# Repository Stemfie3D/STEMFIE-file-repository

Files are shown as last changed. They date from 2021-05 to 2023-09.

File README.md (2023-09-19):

# STEMFIE-file-repository
### The official file repository of the STEMFIE construction-set toy



**STEMFIE** is an open-sourced educational construction-set toy you can download and make using an affordable off-the-shelf 3D printer. 

Inspired by the vintage toy [Meccano](https://en.wikipedia.org/wiki/Meccano), I designed each component as a part of a mechanical ecosystem of compatible shapes defined to interlock through various connections and fasteners.

This file repository contains mainly the three following file types.

* **.STL** - Commonly used for single parts, you can import them into your 3D printer's slicing software or your 3D modeling/CAD software.
* **.3mf** - Commonly used for single parts and ready-to-print nested build plates.
* **.stpZ** - Used for single parts describing the non-destructive shape and form of the part's design. Use this file to import it into your CAD software. If it can't open .stpZ, please download [FreeCAD](https://freecad.org) to open the files.
* **.FCStd** - The original project file of parts and assemblies containing the parametric data for generating the part's shape. FCStd is FreeCAD's native file format.
* **.SVG** - Files describing two-dimensional contours and shapes as vector-based data. Most SVG files in this repository represent 1/4th BlockUnit parts (such as braces) that can be made using a laser cutter.  

The shape and orientation of every STEMFIE file are optimized for 3D printing without the need for support structures on a filament-based 3D printer.

All 3D files and graphics are made in [FreeCAD](https://github.com/FreeCAD/FreeCAD), [Blender](https://github.com/blender/blender), [Inkscape](https://inkscape.org), and [Krita](https://krita.org).

### The STEMFIE Project's Online Places

* [ Official Website](https://stemfie.org)
* [Telegram](http://t.me/stemfie3d)
* [Twitter](https://twitter.com/Stemfie3D)
* [Instagram](https://instagram.com/Stemfie3D)
* [Facebook](https://facebook.com/Stemfie3D)

### Contact Informaiton
* **Paulo Kiefe** (paulo@stemfie.org)

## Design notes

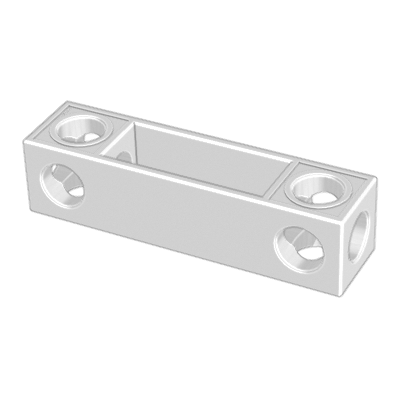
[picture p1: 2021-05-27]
Beams/Straight/Box-section/Beam STR BXS ESS (thumbnail).png

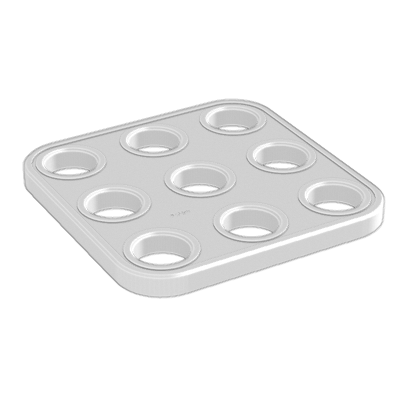
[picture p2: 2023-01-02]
Plates/4 - Square/Plate SQR (thumbnail).png

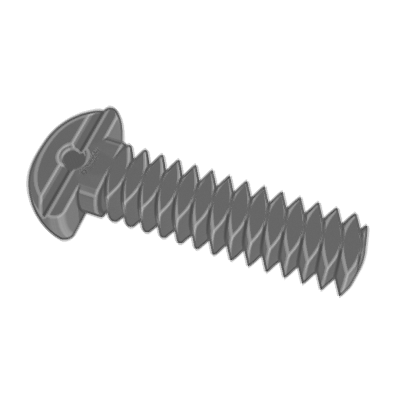
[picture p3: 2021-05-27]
Fasteners/Screws/Fully Threaded Rounded Head/Screw FL-RH RHD (thumbnail).png

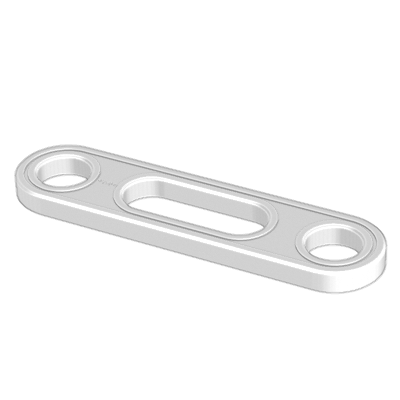
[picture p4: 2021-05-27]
Braces/Straight/Slotted Centered/Brace STR SLT CNT ERR (thumbnail).png

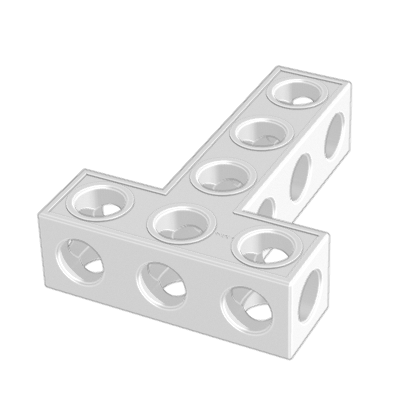
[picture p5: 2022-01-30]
Beams/Angled/T-shaped Symmetric/Beam AGD TSH SYM ESS (thumbnail).png

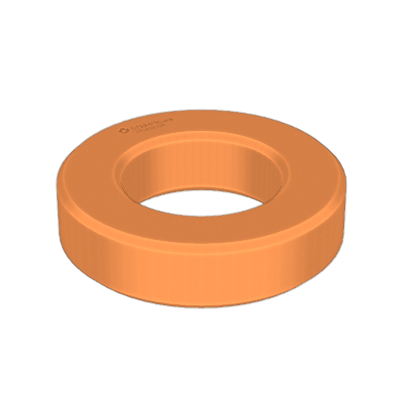
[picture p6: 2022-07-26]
Fasteners/Washers/Free/Washer FRE (thumbnail).png

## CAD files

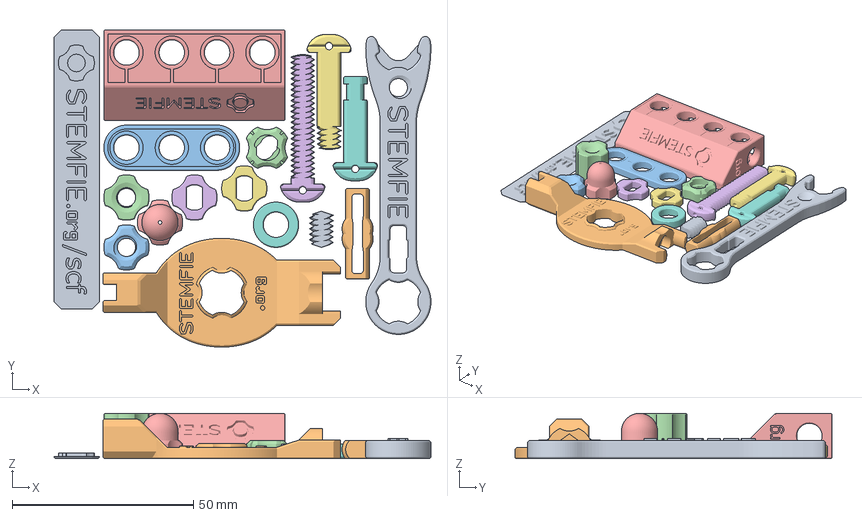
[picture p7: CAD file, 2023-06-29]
3D-printing/Calibration/STEMFIE Calibration File/STEMFIE Calibration File (stemfie.org).3mf
104.0 x 87.5 x 12.5 mm
STEMFIE Calibration File (stemfie.org).stl_1
STEMFIE Calibration File (stemfie.org).stl_2
STEMFIE Calibration File (stemfie.org).stl_3
STEMFIE Calibration File (stemfie.org).stl_4
STEMFIE Calibration File (stemfie.org).stl_5
STEMFIE Calibration File (stemfie.org).stl_6
STEMFIE Calibration File (stemfie.org).stl_7
STEMFIE Calibration File (stemfie.org).stl_8
STEMFIE Calibration File (stemfie.org).stl_9
STEMFIE Calibration File (stemfie.org).stl_10
STEMFIE Calibration File (stemfie.org).stl_11
STEMFIE Calibration File (stemfie.org).stl_12
STEMFIE Calibration File (stemfie.org).stl_13
STEMFIE Calibration File (stemfie.org).stl_14
STEMFIE Calibration File (stemfie.org).stl_15
STEMFIE Calibration File (stemfie.org).stl_16
STEMFIE Calibration File (stemfie.org).stl_17

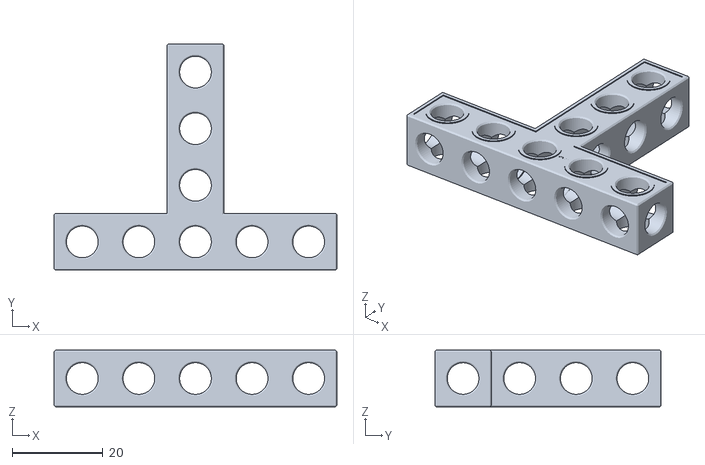
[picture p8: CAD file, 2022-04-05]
Beams/Angled/T-shaped Symmetric/Beam AGD TSH SYM ESS BU05x04x01 - SPN-BEM-1021 (stemfie.org).stl
62.5 x 50.0 x 12.5

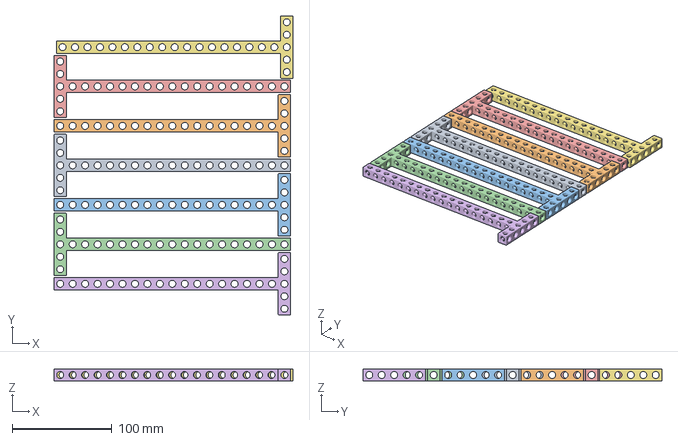
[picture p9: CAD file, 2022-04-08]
Beams/Angled/T-shaped Symmetric/Build Plates/Beam AGD TSH SYM ESS BU05x19x01 - SPN-BEM-1036 (stemfie.org) 7x 3D-printing build plate.3mf
239.9 x 300.0 x 12.5 mm

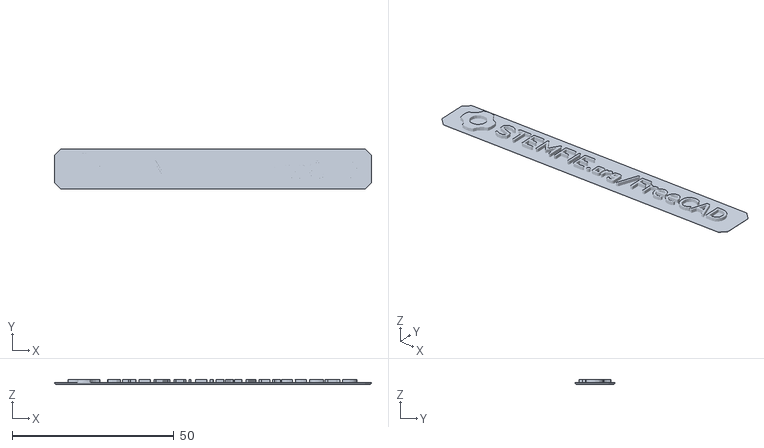
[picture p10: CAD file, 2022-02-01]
Beams/Angled/T-shaped Symmetric/CAD/- You can use the open-source FreeCAD.org software to import and edit .stpZ files.stl
98.0 x 12.5 x 1.56

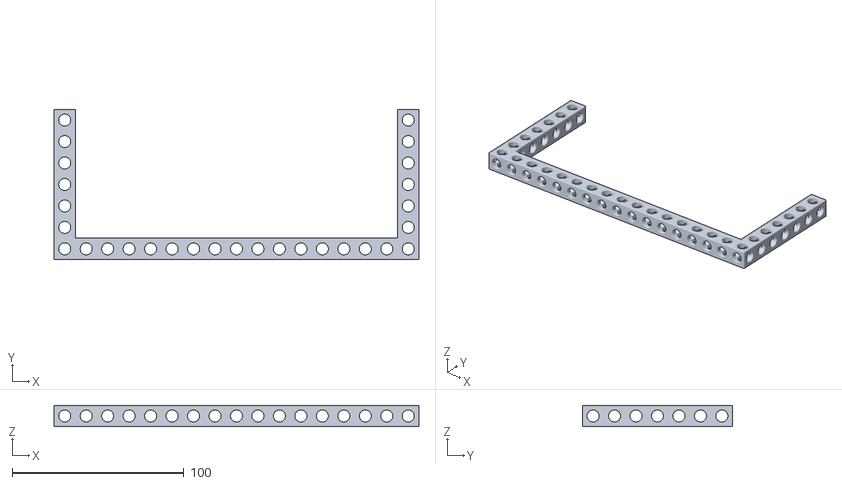
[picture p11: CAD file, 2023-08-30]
Beams/Angled/U-shaped Symmetric/Beam AGD USH SYM ESS BU17x07x01 - SPN-BEM-0580 (stemfie.org).stl
212.5 x 87.5 x 12.5

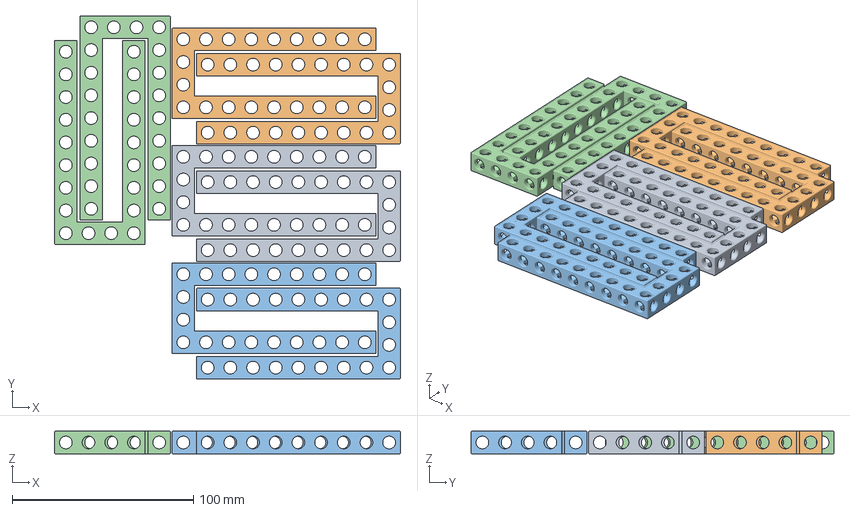
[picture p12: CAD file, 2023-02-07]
Beams/Angled/U-shaped Symmetric/Build Plates/Beam AGD USH SYM ESS BU04x09x01 - SPN-BEM-0327 (stemfie.org) 8x 3D Printing Build Plate.3mf
190.7 x 200.0 x 12.5 mm

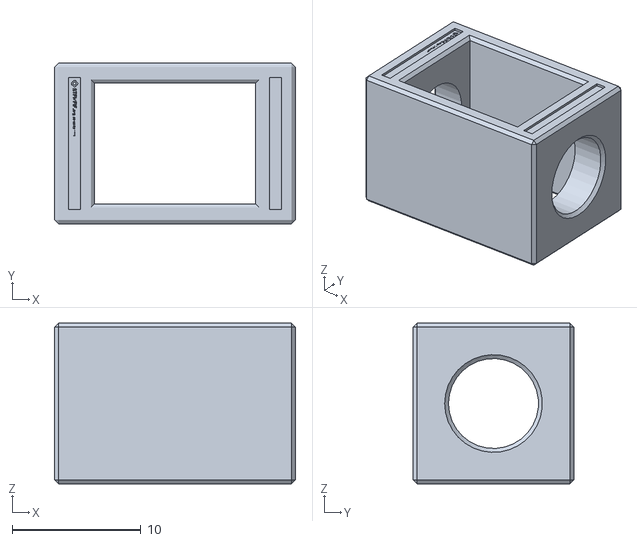
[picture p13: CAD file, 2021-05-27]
Beams/Straight/Box-section/Beam STR BXS ESS BU01.50x01.00x01.00x00.25x00.125 - SPN-BEM-0003 (stemfie.org).stl
18.8 x 12.5 x 12.5

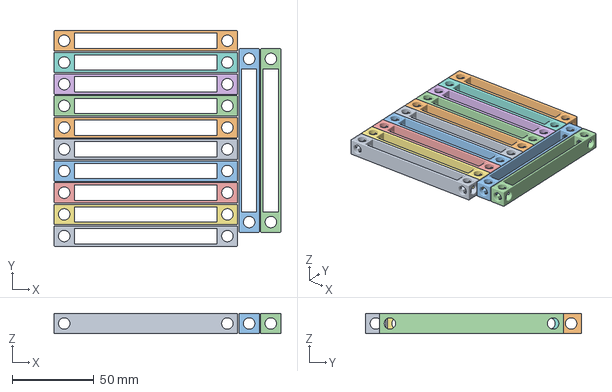
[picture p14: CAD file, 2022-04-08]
Beams/Straight/Box-section/Build Plates/Beam STR BXS ESS BU09.00x01.00x01.00x01.00x00.125 - SPN-BEM-0406 (stemfie.org) 12x 3D-printing build plate.3mf
139.1 x 132.2 x 12.5 mm

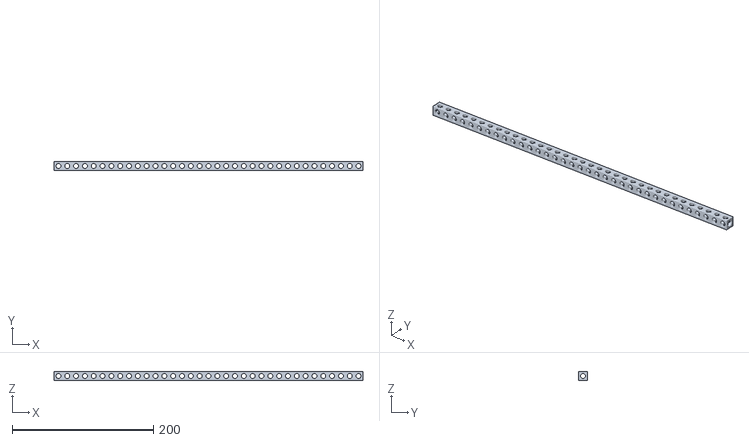
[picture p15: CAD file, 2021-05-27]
Beams/Straight/Square Endings/Beam STR ESS BU35x01x01 - SPN-BEM-0072 (stemfie.org).stl
437.5 x 12.5 x 12.5

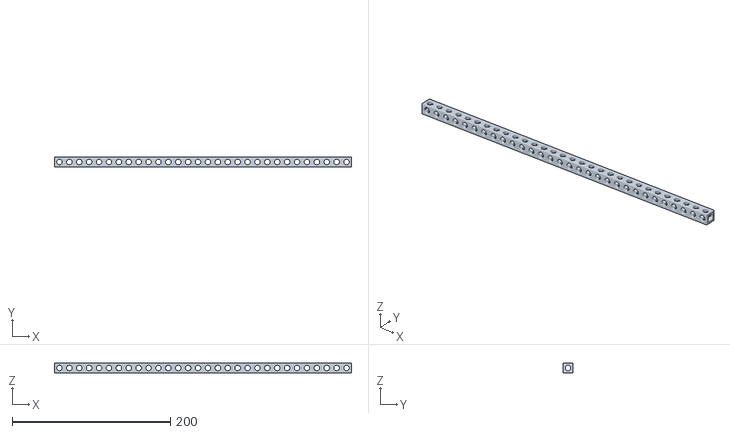
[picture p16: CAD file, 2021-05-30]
Beams/Straight/Square Ends/Beam STR ESS BU30x01x01 - SPN-BEM-0067 (stemfie.org).stl
375.0 x 12.5 x 12.5

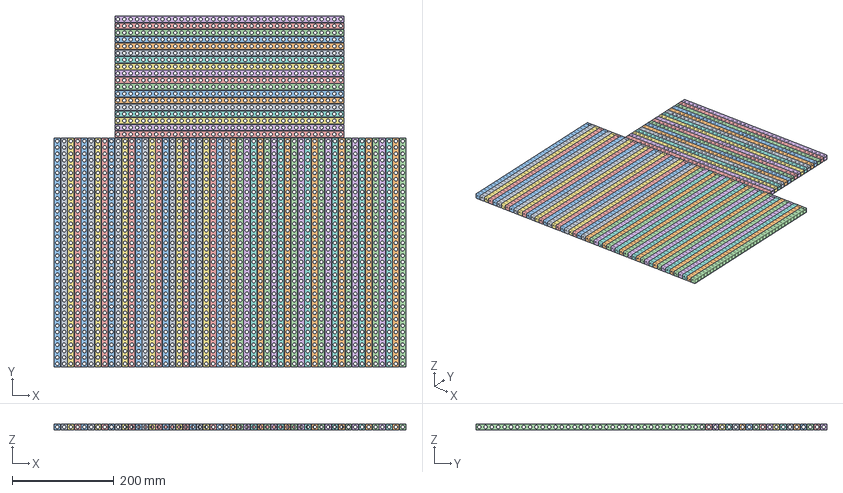
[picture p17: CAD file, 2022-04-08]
Beams/Straight/Square Ends/Build Plates/Beam STR ESS BU36x01x01 - SPN-BEM-0073 (stemfie.org) 70x 3D-printing build plate.3mf
690.8 x 689.4 x 12.5 mm

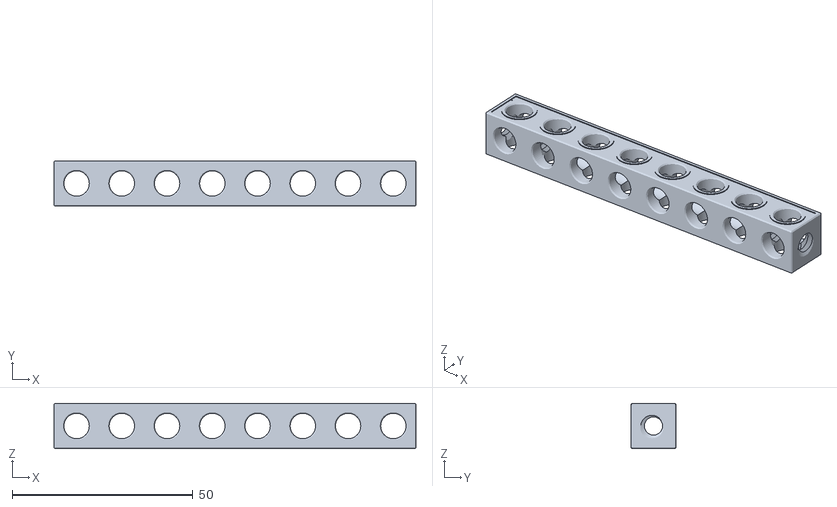
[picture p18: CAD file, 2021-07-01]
Beams/Straight/Threaded Ends/Beam STR ERHRH DE ESS BU08x01x01 - SPN-BEM-0807 (stemfie.org).stl
100.0 x 12.5 x 12.5

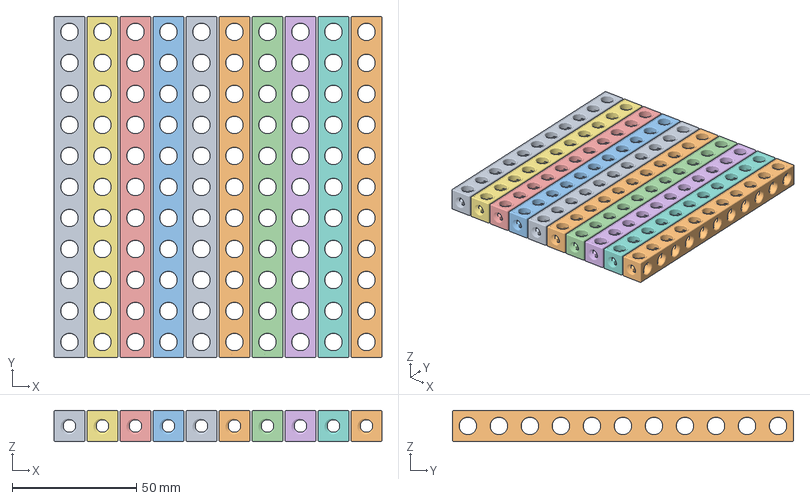
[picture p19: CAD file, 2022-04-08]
Beams/Straight/Threaded Ends/Build Plates/Beam STR ERHRH DE ESS BU11x01x01 - SPN-BEM-0810 (stemfie.org) 10x 3D-printing build plate.3mf
132.2 x 137.5 x 12.5 mm

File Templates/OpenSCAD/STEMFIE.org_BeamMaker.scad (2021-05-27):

//OpenSCAD script for creating Stemife.org construction beams
//Feel free to adapt and improve and share your OpenSCAD script (please send contact me)
//Contact: paulo.kiefe@stemfie.org (https://stemfie.org)


//Number of BlockUnits in the X direction
    BSX=5;
//Number of BlockUnits in the Y direction
    BSY=1; 
//Number of BlockUnits in the Z direction 
    BSZ=1; 
    
//Universal values
    BU=12.5; //Universal voxel block unit (mm) in Stemfie (BlockUnit)
    Hole=3.5; //Universal radius (mm) of the connection hole
    SurfTess=32; //Universal tesselation value of curved surfaces
    ChamferHole=2.45; //Chamfer size adjustment value for connection holes
    ChamferEdge=BU*1.25; //Chamfer size adjustment value for outer edges

difference(){
    cube([BU*BSX, BU*BSY, BU*BSZ]);   
        for(i = [0:BSX-1]){
            translate([i*BU,0,0]) XHoles();
        }
        for(i = [0:BSY-1]){
            translate([0,i*BU,0]) YHoles();
        }
        ZArray();
}



//MODULES
module XHoles(){
    union(){
        translate([BU/2,-ChamferHole,BU/2]) rotate([270,0,0]) cylinder(h=BU/2, r1=BU/2, r2=0, $fn=SurfTess);
        translate([BU/2,ChamferHole+BSY*BU,BU/2]) rotate([90,0,0]) cylinder(h=BU/2, r1=BU/2, r2=0, $fn=SurfTess);
        translate([BU/2,0,BU/2]) rotate([270,0,0]) cylinder(r=Hole, h=BSY*BU, $fn=SurfTess);
    }
}

module YHoles(){
    union(){
        translate([0,BU/2,BU/2]) rotate([0,90,0]) cylinder(r=Hole, h=BSX*BU, $fn=SurfTess);
        translate([-ChamferHole,BU/2,BU/2]) rotate([0,90,0]) cylinder(h=BU/2, r1=BU/2, r2=0, $fn=SurfTess);
        translate([ChamferHole+BSX*BU,BU/2,BU/2]) rotate([0,270,0]) cylinder(h=BU/2, r1=BU/2, r2=0, $fn=SurfTess);
    }
}
module ZHoles(){
    union(){
        translate([BU/2,BU/2,-ChamferHole]) rotate([0,0,0]) cylinder(h=BU/2, r1=BU/2, r2=0, $fn=SurfTess);
        translate([BU/2,BU/2,ChamferHole+BU]) rotate([180,0,0]) cylinder(h=BU/2, r1=BU/2, r2=0, $fn=SurfTess);
        translate([BU/2,BU/2,0]) rotate([0,0,0]) cylinder(r=Hole, h=BU, $fn=SurfTess);
    }
}

module ZArray(){
    for(a = [0:BSX-1]){
        translate([a*BU,0,0]){
            for(i = [0:BSY-1]){
            translate([0,i*BU,0]) ZHoles();
            }
        }
    }
}

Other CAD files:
3D-printing/Samples/STEMFIE.org Quick-print sample/STEMFIE.org Quick-print sample [shoulder-screw, pin, nut, washers, brace].3mf
3D-printing/Samples/STEMFIE.org Quick-print sample/STEMFIE.org Quick-print sample [shoulder-screw, pin, nut, washers, brace].stl
Beams/Angled/T-shaped Symmetric/Beam AGD TSH SYM ESS BU03x02x01 - SPN-BEM-1000 (stemfie.org).stl
Beams/Angled/T-shaped Symmetric/Beam AGD TSH SYM ESS BU03x03x01 - SPN-BEM-1001 (stemfie.org).stl
Beams/Angled/T-shaped Symmetric/Beam AGD TSH SYM ESS BU03x04x01 - SPN-BEM-1002 (stemfie.org).stl
Beams/Angled/T-shaped Symmetric/Beam AGD TSH SYM ESS BU03x05x01 - SPN-BEM-1003 (stemfie.org).stl
Beams/Angled/T-shaped Symmetric/Beam AGD TSH SYM ESS BU03x06x01 - SPN-BEM-1004 (stemfie.org).stl
Beams/Angled/T-shaped Symmetric/Beam AGD TSH SYM ESS BU03x07x01 - SPN-BEM-1005 (stemfie.org).stl
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

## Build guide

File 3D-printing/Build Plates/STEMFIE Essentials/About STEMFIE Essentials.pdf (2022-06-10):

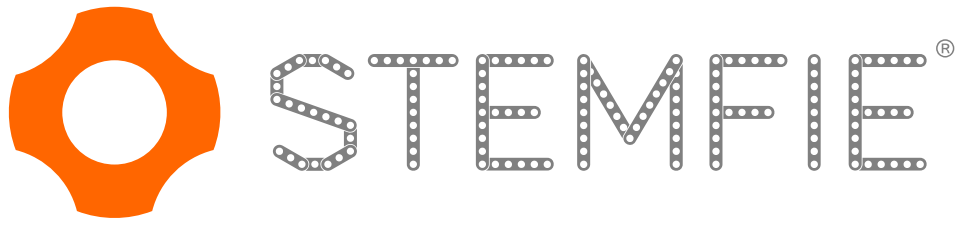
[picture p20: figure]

# About STEMFIE Essentials

This ZIP file contains an assortment of commonly used STEMFIE parts in different sizes nestled into compact build plates measuring less than 140x140x140 mm (5 ½ inches squared), which fits comfortably in most 3D printers' build volume.

Start by importing each .3mf file into your 3D printer's slicing software. All components are oriented to 3D-print optimally without support structures. Please ensure a flat, clean build plate and calibrate it well.

If you use a filament-based 3D printer (FDM/FFF), I recommend PLA or PETG material for making STEMFIE parts. In addition, the following printing settings work well for making STEMFIE parts.

- Material: PLA filament
- Layer height: 0.2 mm
- Perimeters (shells): 3
- Top solid layer count: 4
- Bottom solid layer count: 3
- Infill: 15%
- Generic print speed: 50 mm/s
- No support structures

For more information about the STEMFIE project and to download the complete range of parts, please visit https://stemfie.org/download.

Make sure to be the first to know about new releases of STEMFIE parts and projects! Please subscribe to the newsletter (https://newsletter.stemfie.org) and follow @Stemfie3D #Stemfie3D on social media: https://stemfie.org/news/socialmedia. (https://stemfie.org/news/socialmedia.html)

STEMFIE is a free and open-source educational toy! So have fun 3D-printing lots of parts and inventing your project builds!

Paulo Kiefe
:-)

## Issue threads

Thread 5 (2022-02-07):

Can't clone repository

Cantareus, 2022-02-07:
Hi Paulo, your repository can't be cloned to Windows machines because there are '>‘ characters in some file names:

```
Cloning into 'F:\Github\STEMFIE-file-repository'...
remote: Enumerating objects: 2019, done.
remote: Counting objects: 100% (4/4), done.
remote: Compressing objects: 100% (3/3), done.
remote: Total 2019 (delta 1), reused 1 (delta 1), pack-reused 2015
Receiving objects: 100% (2019/2019), 638.48 MiB | 7.45 MiB/s, done.
Resolving deltas: 100% (775/775), done.
error: invalid path 'Beams/Angled/T-shaped/Symmetric/CAD/-> You can use the open-source FreeCADweb.org software to import and edit .stpZ files.stl'
fatal: unable to checkout working tree
warning: Clone succeeded, but checkout failed.
You can inspect what was checked out with 'git status'
and retry with 'git restore --source=HEAD :/'
```
Cheers,
Brendon

Stemfie3D, 2022-02-08:
Hi Brendon! :)

Thank you for letting me know of this. The file name does not need to have this character and I will change it right away, and also make sure to avoid it in future file names.

Feel free to get in touch with me and give me more feedback at any time.

:-)

Paulo Kiefe
+46734855001
***@***.***
https://STEMFIE.org

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

Cantareus, 2022-02-09:
Awesome, that's done the trick!

Closed 2022-02-09.

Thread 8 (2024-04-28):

Editable source files?

not-surt, 2024-04-28:
Are the original, editable source files available?
The CAD subdirectories under each category mostly just contain STEP files.
I want to make non-square mounting plates for some Arduino modules, and while I can hack up the STEP files of the square plates, I figure it'd be easier to produce different size plates with the original FreeCAD files.
But then I'm not a CAD person so I might well be missing something obvious.

Stemfie3D, 2024-04-28:
Thank you for your suggestion. The core STEMFIE parts are all made in FreeCAD. Nevertheless, it is not practical to release thousands of .fcstd files as a generic STEP/stpZ file usually fits most users' needs.

Please describe in more detail what part you want to adapt for Arduino modules, and I will gladly look into that.

In the meantime, you can download the FreeCAD STEMFIE template file from this link.

https://get.stemfie.org/Templates%20-%20FreeCAD/

not-surt, 2024-04-28:
Available source files is pretty essential to the open source aspect of Stemfie which is a major part of its appeal to me. The STEP format doesn't seem to meet that criteria to me. FreeCAD can't directly edit it, just treats it as a monolithic solid, and other CAD programs seem to be similar.

Surely the beauty of git is that you can just push the FCStd files to the repository at the same time you do the stpZ files?

For the moment I'm just making simple mounting plates, adding screw posts to the appropriately sized plates.
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 (the structure is entirely provided by the battery pack and motor brackets)

casterle, 2024-09-22:
> Available source files is pretty essential to the open source aspect of Stemfie which is a major part of its appeal to me. The STEP format doesn't seem to meet that criteria to me. FreeCAD can't directly edit it, just treats it as a monolithic solid, and other CAD programs seem to be similar.
>
> Surely the beauty of git is that you can just push the FCStd files to the repository at the same time you do the stpZ files?

I agree. Please release the source files for this project.

Obijuan, 2024-09-27:
I agree too. It would be a real opensource project if the sources where available.
Maybe people from the community could create them from scratch. It would be a really good exercise for my students

hasecilu, 2024-10-26:
My 2 cents here:
I'm not totally sure if also having the every source file would be really useful.
1. Having one FreeCAD file per one step/3mf/stl file would be a waste of space. See the example of https://github.com/FreeCAD/FreeCAD-library where we moved from having individual chain/sprocket files to one parametric files. Several GB of disk space were saved.
2. Having one FreeCAD file per one type of component that is able to generate the whole series (configuration table) it's a better choice but still not very practical because you will need to have all the files on your project directory. Fortunately you can have variations.
3. I haven't tested the new VarSet feature but would expect something slightly better than 2, any idea?
4. What I think it's the better option is to have a parametric WB that manages the components separately. Most of the components are part from a series where varying some parameters you can get the size you want but still there are other that are unique (like tools or custom electronics-boxes), in that case a separated file works fine. The main advantage of having object as code is that is easier to share/transmit the components, currently the WB uses 11MB, the https://github.com/Stemfie3D/STEMFIE-file-repository repo weights 7.1GB. Regarding all the step, stl and 3mf files: you can create a macro that generated all those files for you if you wanted it.
5. As you may know already there is a FreeCAD WB for Stemfie, it works fine but is not complete comparing to all current components, so my idea is that would be nice to have the complete system available there, for that, I made a PR to https://github.com/bilbaomakers/StemfieWB/pull/2 doing some maintenance on the code so would be nice if someone else is also interested to complete the missing parts. I'm no expert but already have some parametric-WB experience from the https://github.com/instancezero/in3dca-freegrid WB that I maintain. Later I'll make an example file using the Assembly WB to see how it behaves.
6. I really hope my PR is accepted to continue the development in the same place. Any help there is apreciated.

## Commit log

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2021-05-30 New CAD files in .STPZ format
    [Beam AGD ESS USH SYM BU03x02x01 - SPN-BEM-0301 (stemfie.org).stl, Beam STR ESS BU01x01x01 - SPN-BEM-0038 (stemfie.org).stl, Beam STR ESS BU02x01x01 - SPN-BEM-0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]
2021-06-16 File update
    [Beam AGD ESS USH SYM BU3x2x1 - SPN-BEM-0301 (stemfie.org).stl, Beam STR ESS BU01x01x01 - SPN-BEM-0038 (stemfie.org).stl, Beam STR ESS BU02x01x01 - SPN-BEM-0039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]
2021-10-19 Update containing new parts
    [Beam AGD ESS USH SYM BU05x10x01 - SPN-BEM-0347 (stemfie.org).stl, Beam AGD ESS USH SYM BU07x10x01 - SPN-BEM-0385 (stemfie.org).stl, Beam TSH SYM ESS BU03x08x01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]
2021-10-22 New STEMFIE parts
    [Holder SPH LOP BRG-SCT INR-DIA BU02.50x02.00x01.50x01.25 - SPN-HLD-0007 (stemfie.org).stl, Holder Trigger BEM BU07x03x00.25 - SPN-HLD-0200 (stemfie.org).stl, K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]
2022-01-30 T-shaped beams
    [Beam TSH SYM ESS BU03x02x01 - SPN-BEM-1000 (stemfie.org).stl, Beam TSH SYM ESS BU03x03x01 - SPN-BEM-1001 (stemfie.org).stl, Beam TSH SYM ESS BU03x04x01 - SPN-B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]
2022-01-31 Name change
    [Beam AGD ESS USH SYM BU03x02x01 - SPN-BEM-0301 (stemfie.org).stl, Beam AGD ESS USH SYM BU05x10x01 - SPN-BEM-0347 (stemfie.org).stl, Beam AGD ESS USH SYM BU07x1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]
2022-02-01 Updated folder structure
    [-> You can use the open-source FreeCADweb.org software to import and edit .stpZ files.stl, Beam STR ESS BU01x01x01 - SPN-BEM-0038 (stemfie.org) 100x 3D-printin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]
2022-02-03 STEMFIE Construction-Standard Template
    [-> You can use the open-source FreeCADweb.org software to import and edit .stpZ files.stl, STEMFIE Construction-Standard Template Block Unit BU01x01x01 - SCT-0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]
2022-02-09 File name changes
    [- You can use the open-source FreeCADweb.org software to import and edit .stpZ files.stl, Brace AGD 90 ASYM ERR BU02x03x01x00.25 - SPN-BRC-1000 (stemfie.org).s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]
2022-02-09 Folder update
    [Beam TSH SYM ESS BU03x04x01 - SPN-BEM-1002 (stemfie.org).FCStd]
2022-02-10 Brace AGD 90 ASYM ERR
    [Brace AGD 90 ASYM ERR BU05x12x01x00.25 - SPN-BRC-1057 (stemfie.org).stl, Brace AGD 90 ASYM ERR BU05x13x01x00.25 - SPN-BRC-1058 (stemfie.org).stl, Brace AGD 90 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]
2022-02-20 Build plates from .stl to 3mf format
    [- You can use the open-source FreeCADweb.org software to import and edit .stpZ files.stl, Beam AGD ESS USH SYM BU03x03x01 - SPN-BEM-0302 (stemfie.org).stl, Bea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]
2022-03-13 Create N20 Geared Motor.FCStd
    WIP version of the N20 motor enclosure
    [N20 Geared Motor.FCStd]
2022-03-13 WIP update with more block unit holes
    [Body.stl, Clamp.stl, N20 Geared Motor.FCStd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]
2022-03-14 Update containing M5 nuts
    [Body.stl, Clamp.stl, Pulley.stl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]
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2022-04-08 Create Pin SPP INR LCT BDR BU01.00x00.50 - SPN-PIN-0094 (stemfie.org) 75x 3D-printing build plate.3mf
    [Pin SPP INR LCT BDR BU01.00x00.50 - SPN-PIN-0094 (stemfie.org) 75x 3D-printing build plate.3mf]
2022-04-08 New build plates
    [Beam STR BXS ESS BU01.00x01.00x01.00x00.25x00.125 - SPN-BEM-0001 (stemfie.org) 100x 3D-printing build plate.3mf, Beam STR BXS ESS BU01.25x01.00x01.00x00.25x00.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]
2022-06-08 Screw build plates as .3mf
    [Screw RHD RH BU00.25 - SPN-SCR-0081 (stemfie.org) 40x 3D-printing build plate.3mf, Screw RHD RH BU00.50 - SPN-SCR-0082 (stemfie.org) 40x 3D-printing build plat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]
2022-06-09 Build plates and .stpz files
    [Screw RHD RH BU02.00 - SPN-SCR-0088 (stemfie.org) 40x 3D-printing build plate.3mf, Screw RHD RH BU02.00 - SPN-SCR-0088 (stemfie.org) 40x 3D-printing build plat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]
2022-06-20 Quick-print sample update
    [Nut PH CL BU1x5mm - SPN-NUT-0018 (stemfie.org).stl, STEMFIE.org - Quick-print sample parts (shoulder-screw, pin, nut, washers, brace).stl, STEMFIE.org Quick-pr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]
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2022-07-04 File and folder structure update
    [- You can use the open-source FreeCADweb.org software to import and edit .stpZ files.stl, Brace AGD 90 ASYM ERR BU02x03x01x00.25 - SPN-BRC-1000 (stemfie.org).s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]
2022-07-12 Restructure of files and folders
    [- You can use the open-source FreeCADweb.org software to import and edit .stpZ files.stl, Nut PH CL BU01.00x00.25 - SPN-NUT-0019 (stemfie.org).stl, Nut PH CL B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]
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2023-01-10 Changes in file structure and names
    [- You can use the open-source FreeCADweb.org software to import and edit .stpZ files.stl, Screw FL-RH RHD BU00.25 - SPN-SCR-0081 (stemfie.org) 40x 3D-printing 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]
2023-01-19 Adding new build plates
    [Nut CPN RH BU01x01.00 - SPN-NUT-0035 (stemfie.org) 121x 3D-printing build plate.3mf, Nut CPN RH BU01x01.25 - SPN-NUT-0036 (stemfie.org) 121x 3D-printing build 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]
2023-04-05 Update Tool Spanner NUT - SPN-TOL-0004 (stemfie.org).stl
    [Tool Spanner NUT - SPN-TOL-0004 (stemfie.org).stl]
2023-04-06 Nerf gun dart file update
    [Nerf Dart Blunt 13 x 73 mm - SPN-NPH-0003 (stemfie.org).FCStd, Nerf Dart Blunt 13 x 73 mm - SPN-NPH-0003 (stemfie.org).stl]
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2023-06-01 Update Nut PH CL BU01.00x5mm - SPN-NUT-0018 (stemfie.org).stl
    [Nut PH CL BU01.00x5mm - SPN-NUT-0018 (stemfie.org).stl]
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2023-09-06 Updated to 5 mm fasteners
    [Tool Spanner NUT - SPN-TOL-0004 (stemfie.org).stl]
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
